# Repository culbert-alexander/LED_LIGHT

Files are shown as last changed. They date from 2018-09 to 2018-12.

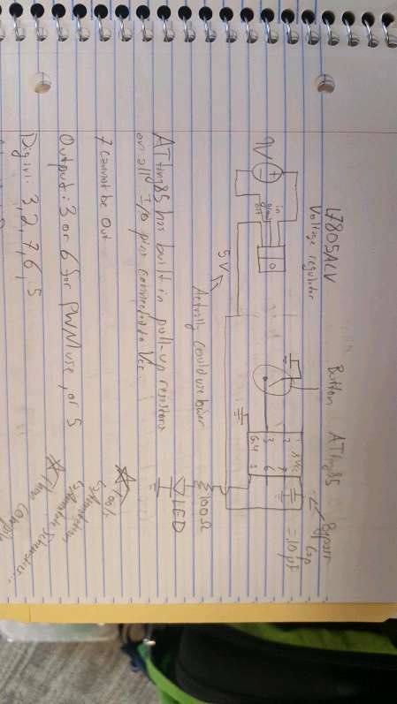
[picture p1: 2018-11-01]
Electronics/circuit.jpg

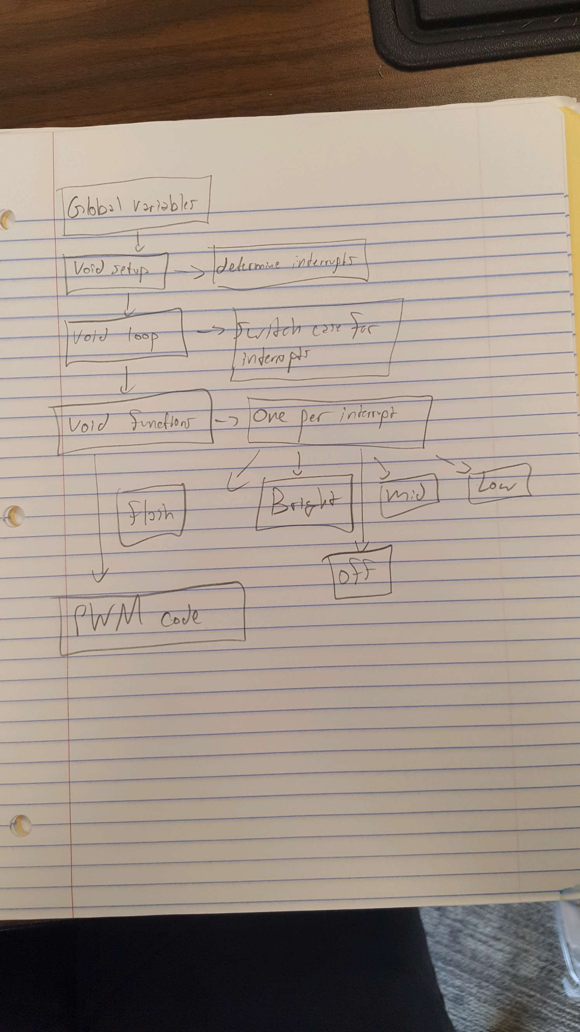
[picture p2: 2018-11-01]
Software/software.jpg

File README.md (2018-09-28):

# LED_LIGHT
Project for Duke University BME 590L
Goal is to build a self-contained batery powered variable light intensity LED.
Must have button exposed.
Must have 5 settings: off, bright, medium bright, low bright, flash at 2 hz.
Certain constraints: <= 9 V, <= 1 lb, < 6 in, <= $50, single PCB, replaceable battery

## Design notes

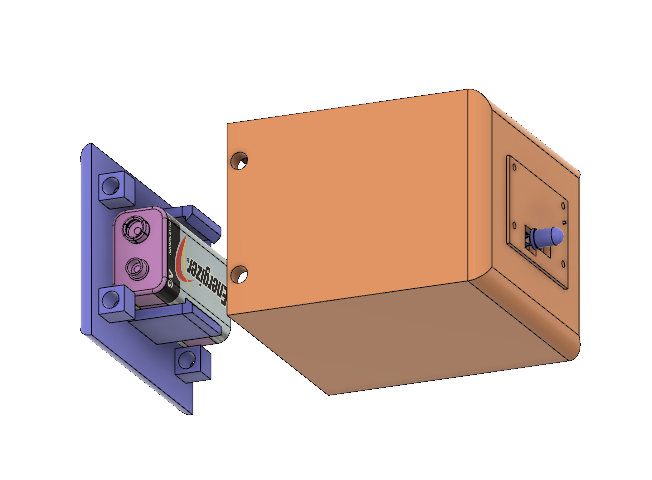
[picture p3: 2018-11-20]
Mechanical/Case_Image.PNG

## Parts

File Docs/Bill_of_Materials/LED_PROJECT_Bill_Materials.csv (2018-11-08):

Comment | Description | Designator | Footprint | LibRef | Quantity
SSW-104-02-T-D | SQ Post Socket, Through-hole, Vertical, -55 to 105 degC, 2.54mm Pitch, 8-Pin, Female, RoHS | ATTiny | SMTC-SSW-104-02-X-D | CMP-1023-00342-1 | 1
147694-1 | FSM8JRT=SWITCH,PUSHBUTTON,TACT | Button | TE_FSM8JRT | FSM8JRT | 1
81R0LFJ0511WPN081T | Aluminum Electrolytic Capacitor, 1 uF +/- 5%, 50 V, -40 to 105 degC, 2 Pin THD, Dia 5 mm, Body Length 11 mm, Tape and Reel | ByCap | FHTE-8-0511-2_M | CMP-0909-00001-1 | 1
151053RS03000 | THT LED round mono-color waterclear, WL-TMRW ,Red | LED | Type 5mm | CMP-1489-00007-1 | 1
FMP300FRF73-82K | Metal Film Resistor, 82 KOhm +/-1%, 3 W, -55 to 155 degC, 2-Pin THD, RoHS, Tape and Reel | LEDR | YAGO-FMP300-2_V2 | CMP-1257-00001-1 | 1
PHF-102-01-L-S-002 | Press Fit Socket, Through-hole, Vertical, -55 to 125 degC, 2.54 mm Pitch, 2-Pin, Female, RoHS | Power | SMTC-PHF-102-01-X-S-002 | CMP-1023-00103-1 | 1
L7805ACV | Positive Voltage Regulator, 5V, 3-Pin TO-220 | PowerReg | TO220 | CMP-0244-00484-1 | 1

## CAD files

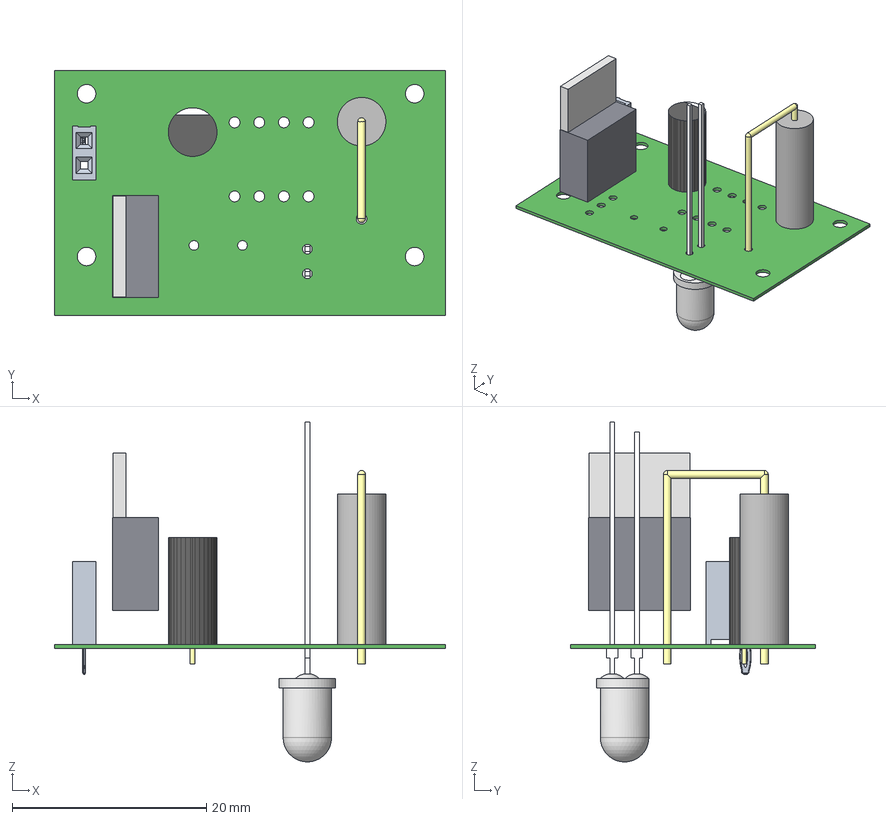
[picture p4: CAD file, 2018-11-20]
Hardware/LED_PROJECT.step
40.3 x 25.3 x 35.0 mm
Board
PHF-102-01-X-S-002
Extruded x 4
WL-TMRW_5mm

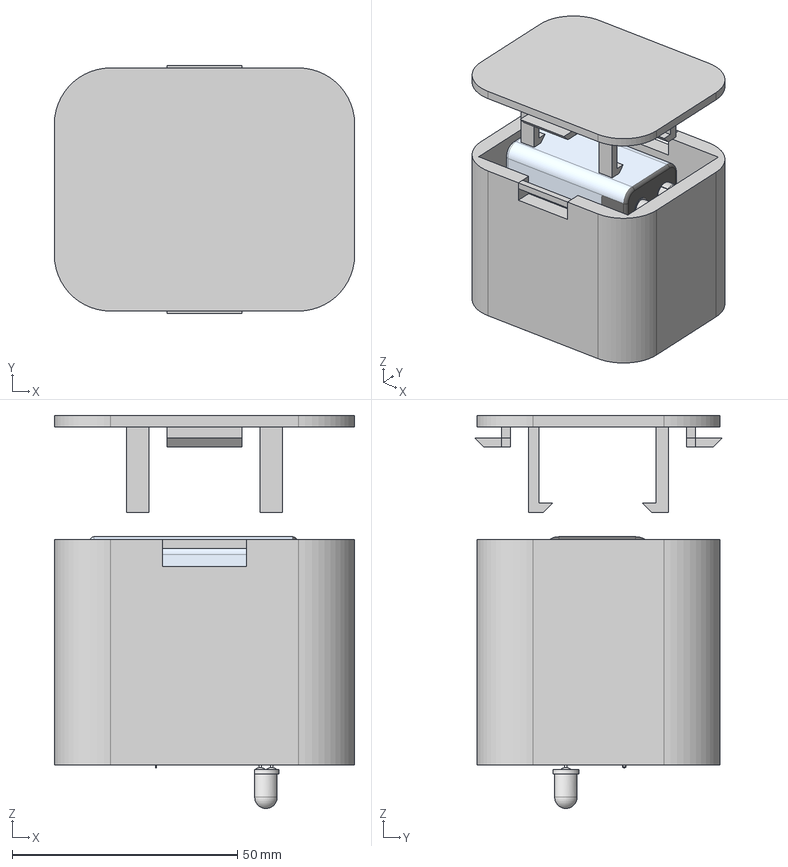
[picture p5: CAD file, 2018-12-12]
Mechanical/Light_Case_2.0.step
66.7 x 55.0 x 87.2 mm
Board
PHF-102-01-X-S-002
Extruded
Extruded (1)
WL-TMRW_5mm
Extruded (2)
Extruded (3)
Siding
9V_1
Lid (1)

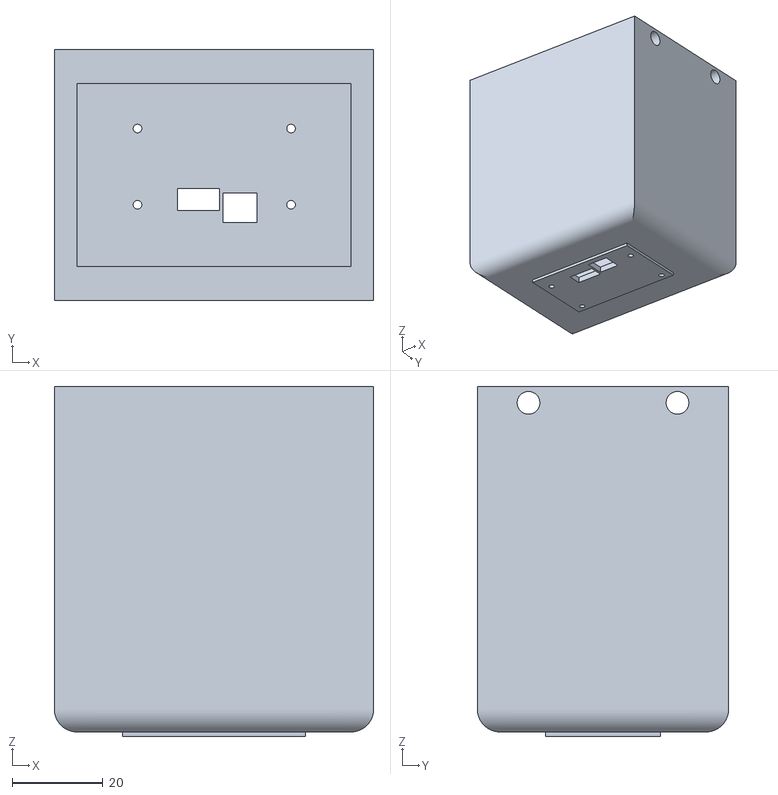
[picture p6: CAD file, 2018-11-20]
Mechanical/Face.stl
70.3 x 55.3 x 77.0

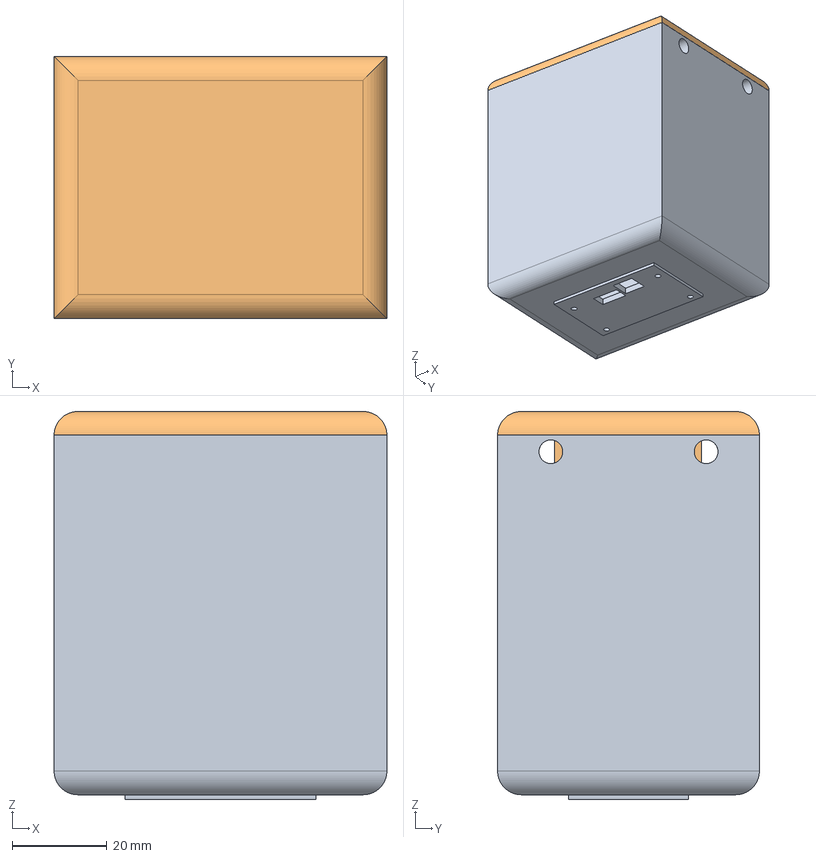
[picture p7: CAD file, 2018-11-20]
Mechanical/LED_PROJECT v9.step
70.3 x 55.3 x 81.9 mm
Lid

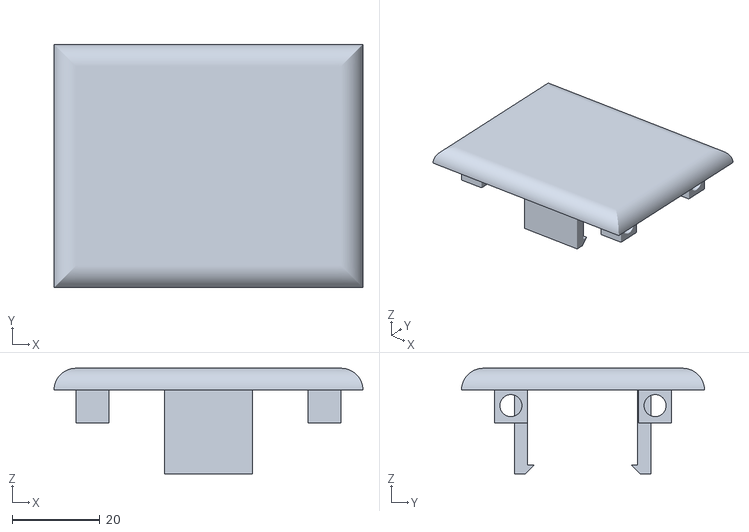
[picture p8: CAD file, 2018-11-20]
Mechanical/Lid.stl
70.3 x 55.3 x 24.0

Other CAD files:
Mechanical/Face.f3d
Mechanical/Lid.f3d

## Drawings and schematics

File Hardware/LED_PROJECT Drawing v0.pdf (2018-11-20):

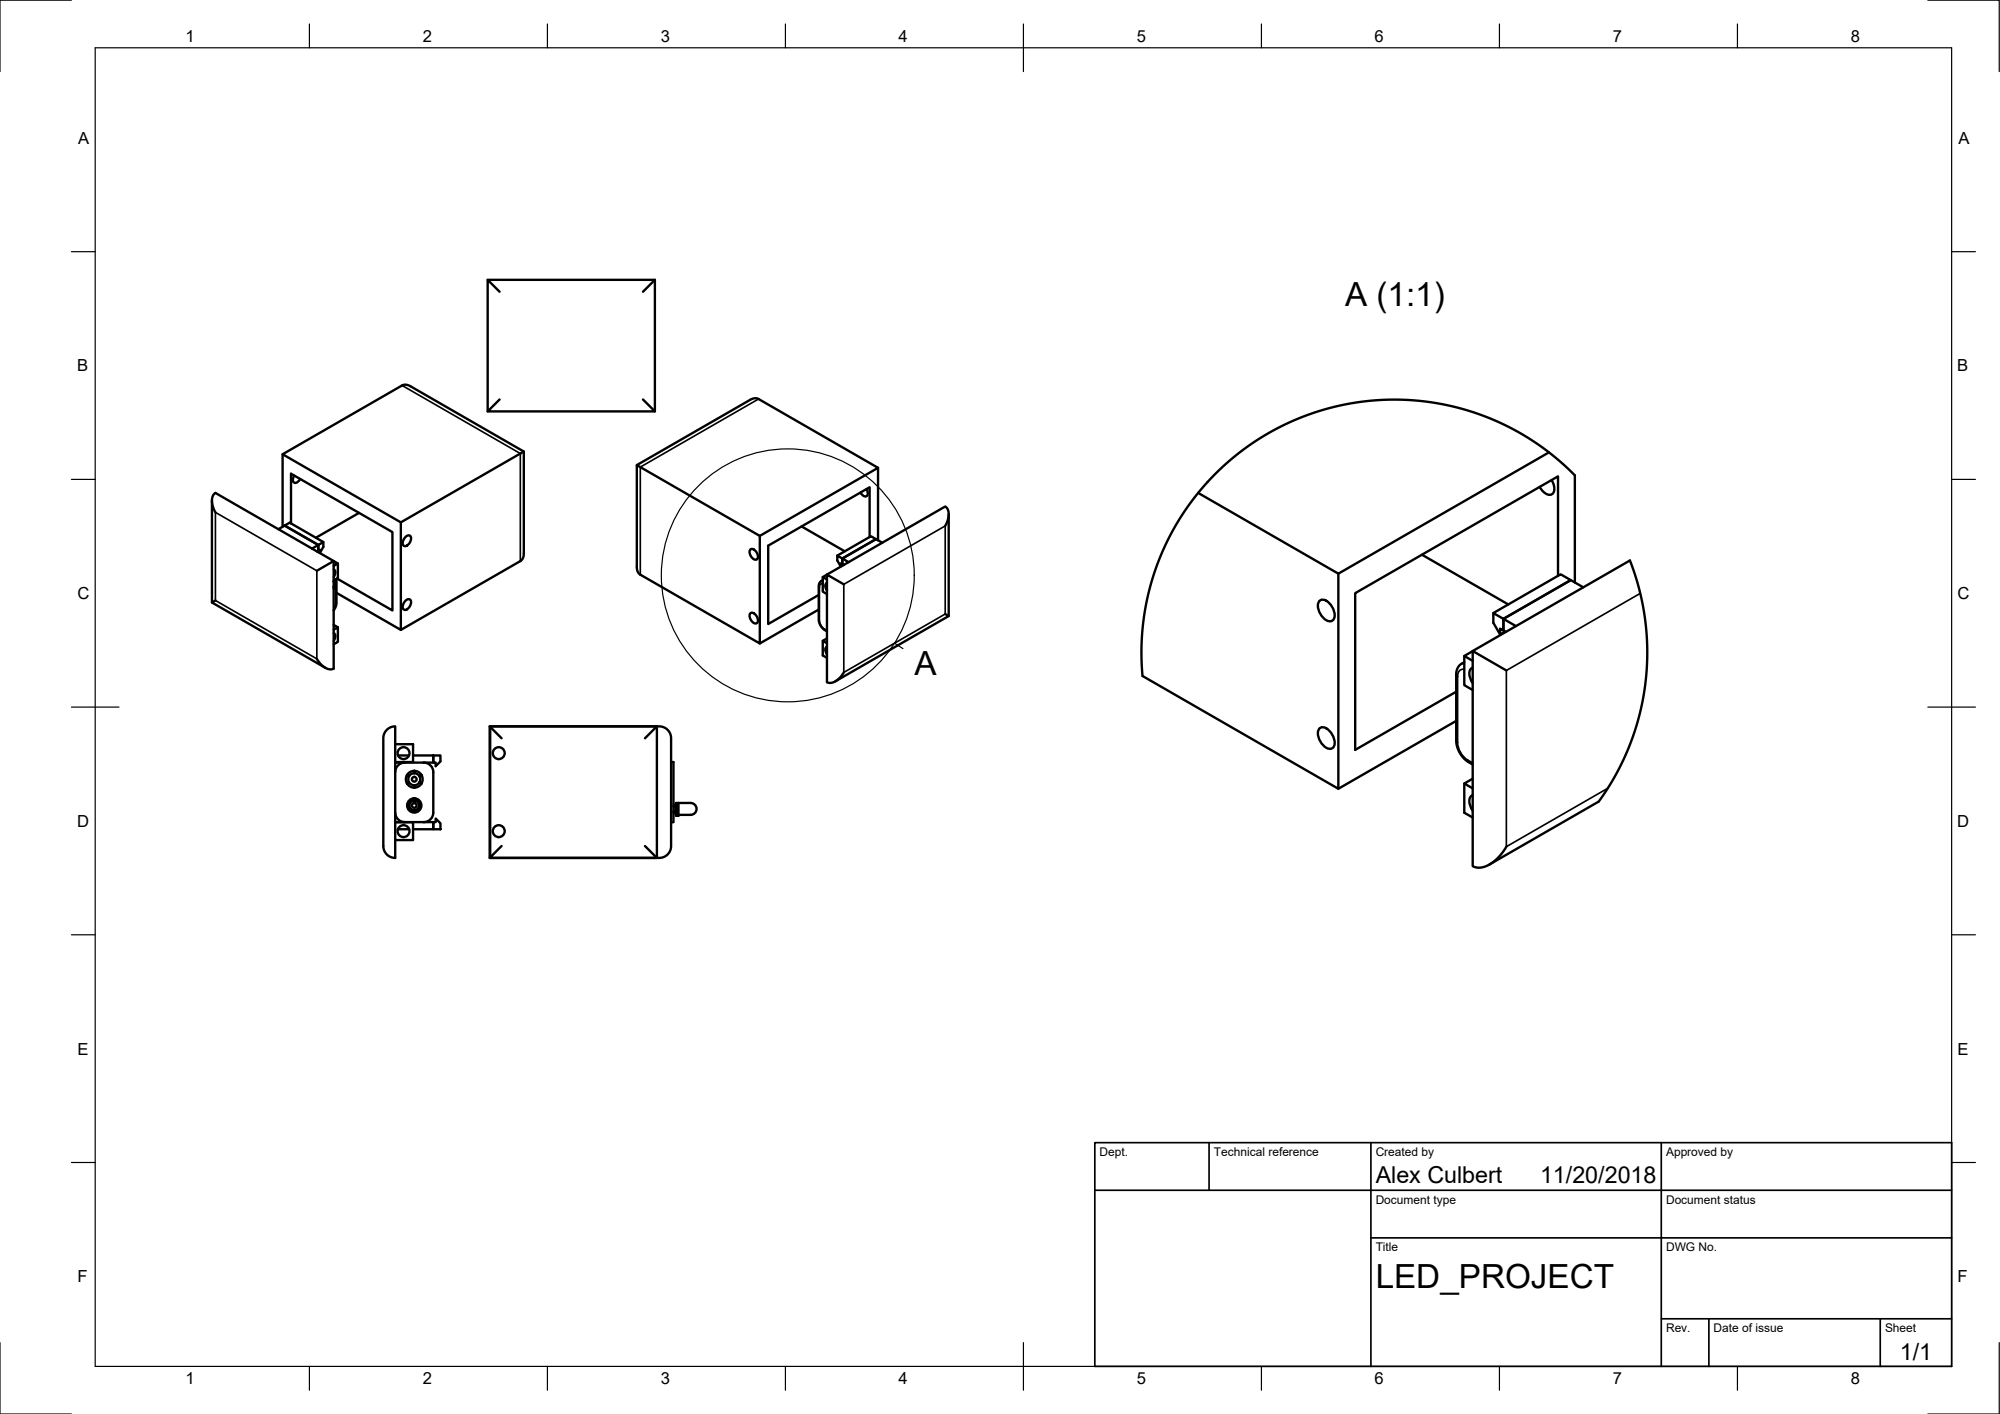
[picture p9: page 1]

Dept. | Technical reference | Created by Alex Culbert 11/20/2018 | Approved by

Document type | Document status

Title LED_PROJECT | DWG No.

Rev. | Date of issue | Sheet 1/1

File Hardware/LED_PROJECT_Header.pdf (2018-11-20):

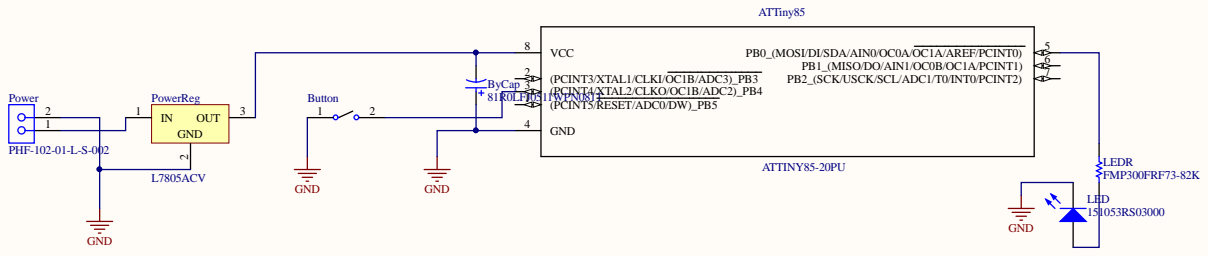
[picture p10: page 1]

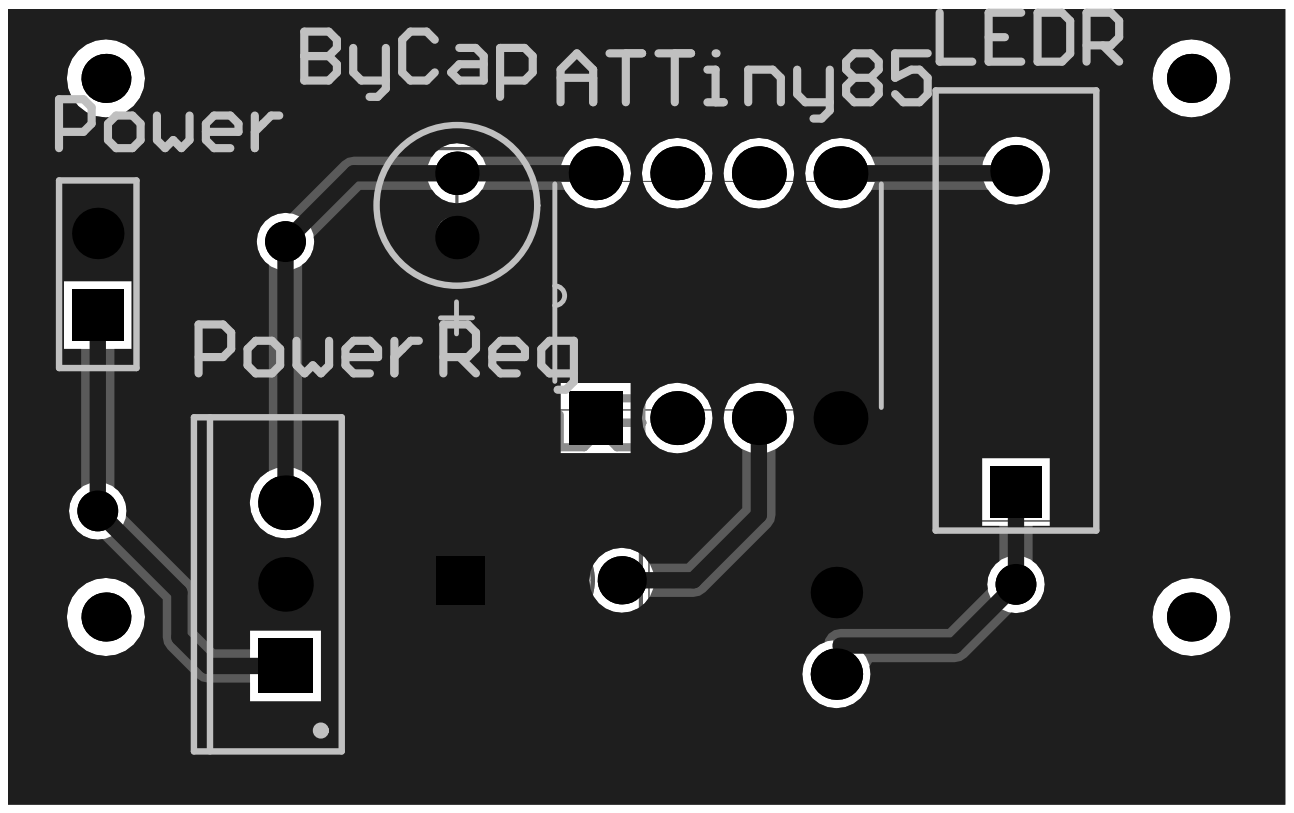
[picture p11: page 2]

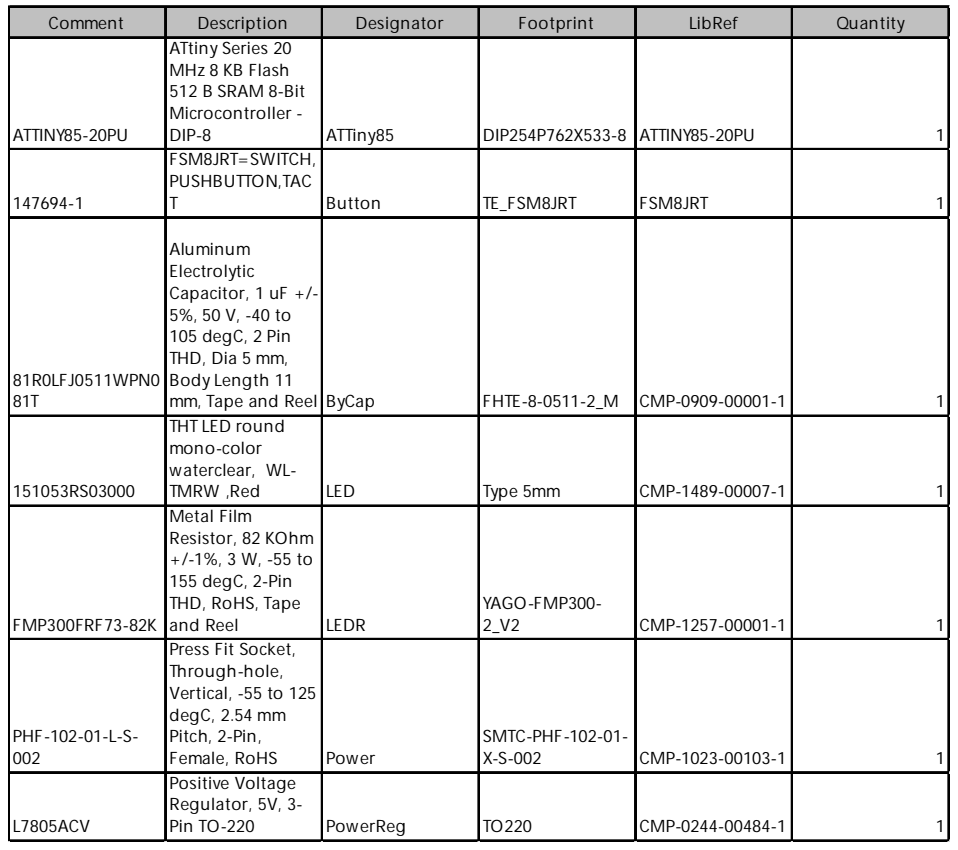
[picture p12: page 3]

Comment | Description | Designator | Footprint | LibRef | Quantity
ATTINY85-20PU | ATtiny Series 20 MHz 8 KB Flash 512 B SRAM 8-Bit Microcontroller -DIP-8 | ATTiny85 | DIP254P762X533-8 | ATTINY85-20PU | 1

147694-1 | FSM8JRT=SWITCH, PUSHBUTTON,TAC T | Button | TE_FSM8JRT | FSM8JRT | 1

81R0LFJ0511WPN0 81T | Aluminum Electrolytic Capacitor, 1 uF +/-5%, 50 V, -40 to 105 degC, 2 Pin THD, Dia 5 mm, Body Length 11 mm, Tape and Reel | ByCap | FHTE-8-0511-2_M | CMP-0909-00001-1 | 1

151053RS03000 | THT LED round mono-color waterclear, WL-TMRW ,Red | LED | Type 5mm | CMP-1489-00007-1 | 1

FMP300FRF73-82K | Metal Film Resistor, 82 KOhm +/-1%, 3 W, -55 to 155 degC, 2-Pin THD, RoHS, Tape and Reel | LEDR | YAGO-FMP300-2_V2 | CMP-1257-00001-1 | 1

PHF-102-01-L-S-002 | Press Fit Socket, Through-hole, Vertical, -55 to 125 degC, 2.54 mm Pitch, 2-Pin, Female, RoHS | Power | SMTC-PHF-102-01-X-S-002 | CMP-1023-00103-1 | 1

L7805ACV | Positive Voltage Regulator, 5V, 3-Pin TO-220 | PowerReg | TO220 | CMP-0244-00484-1 | 1

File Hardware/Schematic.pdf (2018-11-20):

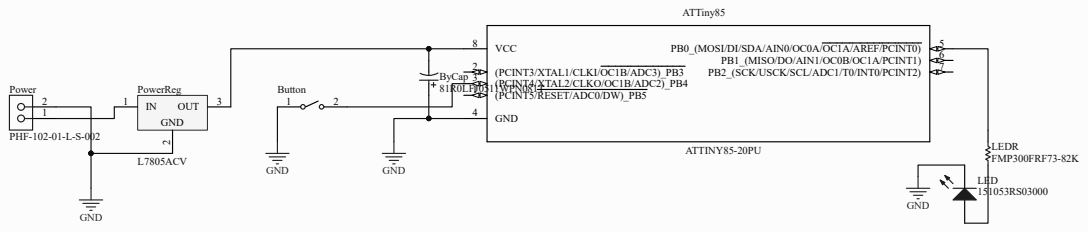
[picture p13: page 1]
Title; OUT; GND; PowerReg; L7805ACV; Power; PHF-102-01-L-S-002; LED 151053RS03000; LEDR FMP300FRF73-82K; Button; ByCap 81R0LFJ0511WPN081T; PB2_(SCK/USCK/SCL/ADC1/T0/INT0/PCINT2); 7 PB1_(MISO/DO/AIN1/OC0B/OC1A/PCINT1); 6 PB0_(MOSI/DI/SDA/AIN0/OC0A/OC1A/AREF/PCINT0); GND 4; (PCINT5/RESET/ADC0/DW)_PB5 1; (PCINT4/XTAL2/CLKO/OC1B/ADC2)_PB4 3; (PCINT3/XTAL1/CLKI/OC1B/ADC3)_PB3 2; VCC 8; ATTiny85; ATTINY85-20PU

Size Letter | Number | Revision

Date: 11/20/2018 | Sheet of
File: C:\Data\..\LED_PROJECT.SchDoc | Drawn By:

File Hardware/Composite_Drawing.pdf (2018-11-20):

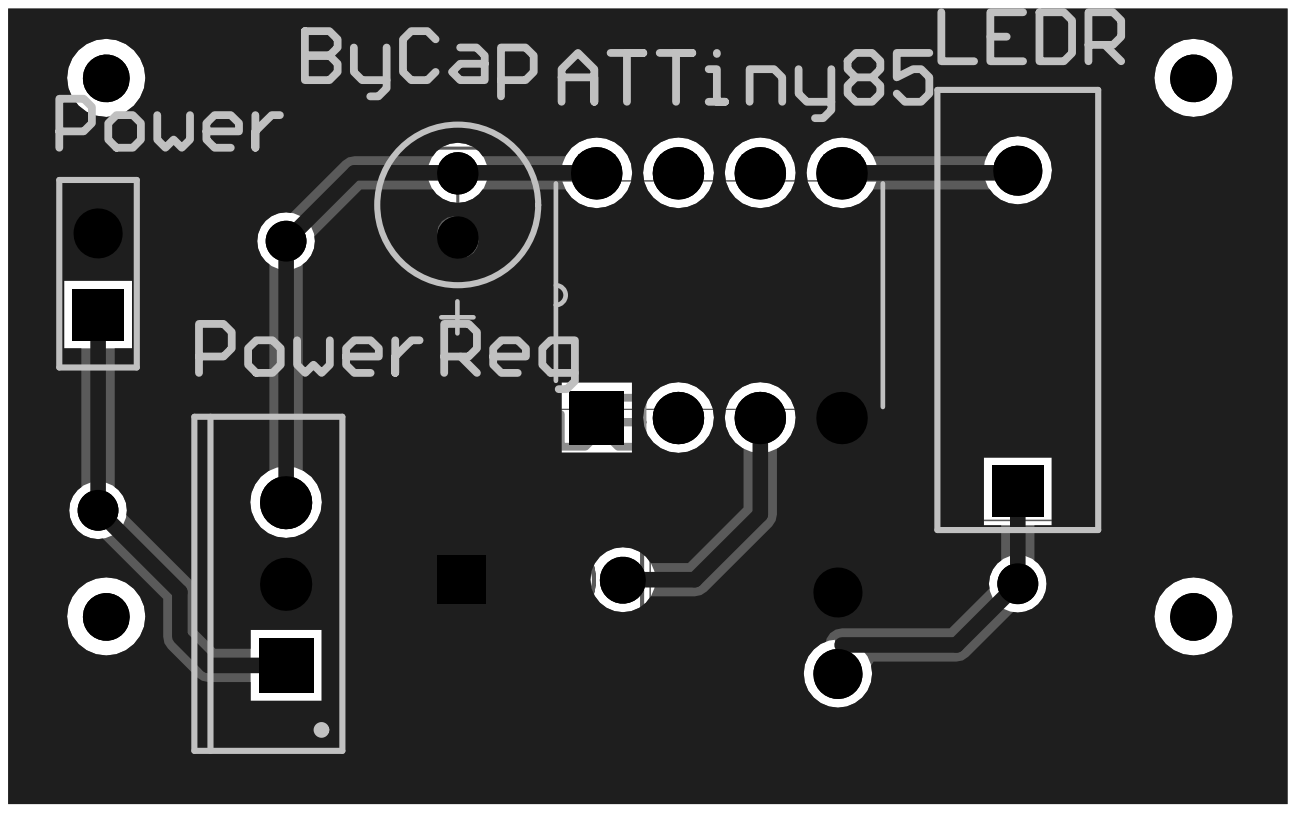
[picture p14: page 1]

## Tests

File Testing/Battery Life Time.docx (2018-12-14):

Alexander Culbert

12-14-2018

BME 590L

Battery Life Time

Battery capacity for a 9V = 500 mAh.

Battery drain at rest: 5.57 mA

Battery drain at high: 17.93 mA

In an ideal situation:

Max battery life time while at rest:

500 mAh / 5.57 mA = 89 hours and 46 minutes

Max battery life time while operating at high:

500 mAh / 17.93 mA = 27 hours and 53 minutes

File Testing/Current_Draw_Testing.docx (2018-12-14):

Alexander Culbert

12-14-2018

BME 590L

Current Draw Testing

At rest: 5.57 mA

At low: 9.54 mA

At medium: 12.41 mA

At high: 17.93 mA

Flashing 6.81, 17.93 mA alternating

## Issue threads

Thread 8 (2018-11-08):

Milestone 04 PCB

culbert-alexander, 2018-11-08:
Hopefully the PCB is at a good start. Known issues may be the clearance, and whether or not the bottom layer is actually all copper. I plan on using through-hole for everything. MCU code to come later once I figure out ATTiny.

sphaerobolus, 2018-11-12:
FYI, our ATTinys are SMT.

The 2-row header you've used for the Tiny is a recipe for a headache. Best to use the correct footprint.

Don't need to parallel traces on top and bottom of board. Put a trace on either side, but not both.

Bypass cap should be close to the Tiny's power pin, between pin and ground. The bypass cap here is in between power supply and the Tiny's power pin. This will block the DC power, no good.

brinnaebent, 2018-11-12:
Why do you have a route on top/bottom (the same route?). It looks like you shouldn't need that 2nd layer at all.
Connections okay.
Consider clearance around header for whatever microcontroller you are plugging into it.

culbert-alexander, 2018-11-20:
PCB should be all but fixed at this point. Please note I'm using through-hole ATTiny85s that I bought and plan on soldering a socket in. The footprint chosen was pulled from DigiKey's ATTiny85 library.

sphaerobolus, 2018-11-20:
Looks good now. One thing we must have missed before: I don't see a pullup or pulldown resistor on your momentary switch. Do you have an internal?

culbert-alexander, 2018-11-20:
Yep planning on using the ATTiny85's internal pullup resistors

culbert-alexander, 2018-11-30:
Shorted my PCB soldering. Feeling very foolish now...

mlp6, 2018-11-30:
Uh oh... salvageable?

culbert-alexander, 2018-12-03:
Unclear. I believe having the top plate being ground with little traces for everything else has caused me to have significant overlap in my solder between the trace and the large ground plate. Thus, the short. I've attached a picture of my PCB, though I know just looking at it may not help.
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

At this point, is my best move to slightly redo my PCB with a ground trace connecting all the grounds, versus the top plate? This would allow my soldering to be this messy and not connect any pins to ground (assuming my assumption here is correct, in that that's the issue).

brinnaebent, 2018-12-03:
Hi Alex,

I think your issue is definitely messy soldering. The solder should be a small bubble and shouldn’t overlap with the rest of your board. From the picture, it looks like you are shorted in at least 3 places. I think your best bet is to re-do the board and be very thoughtful when soldering your next board.

On Dec 2, 2018, at 9:59 PM, Alexander Culbert <notifications@github.com<mailto:notifications@github.com>> wrote:

Unclear. I believe having the top plate being ground with little traces for everything else has caused me to have significant overlap in my solder between the trace and the large ground plate. Thus, the short. I've attached a picture of my PCB, though I know just looking at it may not help.
[img_4999]<https://urldefense.proofpoint.com/v2/url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>

At this point, is my best move to slightly redo my PCB with a ground trace connecting all the grounds, versus the top plate? This would allow my soldering to be this messy and not connect any pins to ground (assuming my assumption here is correct, in that that's the issue).

—
You are receiving this because you commented.
Reply to this email directly, view it on GitHub<https://urldefense.proofpoint.com/v2/url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>, or mute the thread<https://urldefense.proofpoint.com/v2/url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>.

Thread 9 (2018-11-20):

Milestone 05 CAD

culbert-alexander, 2018-11-20:
The mechanical casing should be at a good starting point. I was unable to upload the entire Fusion 360 project due to the 9V battery component I imported, but I have STLs and .f3d files for my lid and main-base. I plan on having some simple screw to connect the PCB to the case and the lid to the main-base.

ps178, 2018-11-23:
Can you move the CAD files under the folder Mechanical as instructed for milestone 05?

I think your CAD looks good! It might be too tall? But you can adjust that when you have the physical PCB, etc.

culbert-alexander, 2018-11-25:
Yup that's on me, my bad! The CAD files are now under Mechanical.
And the longest dimension is 3 inches, I think the picture makes it look a lot longer than it really is!

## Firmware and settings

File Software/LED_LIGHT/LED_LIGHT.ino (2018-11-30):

// I was inspired by online resources from https://thewanderingengineer.com/2014/08/11/pin-change-interrupts-on-attiny85/
// This guy is Matt Walker at University of Oklahoma
// I also used the ATTiny85 Datasheet a whole bunch
// Finally, Dr. Palmeri's example code at https://github.com/mlp6/Fundamentals-BME-Design/blob/master/PrototypingSkills/software.ino
// Besides their help the rest is me at Alexander Culbert

#include <avr/io.h>
#include <avr/interrupt.h>
#include <avr/sleep.h>

// Look at me preprocess whoo whoo woooo
#define PIN_OUT PCINT0    // Pin 0
#define PIN_IN PCINT4     // Pin 4
#define PWM_Max_Val 255   // PWM Max is 255

// The initial, changeable values
int current_mode = 0;     // 0 = Off, 1 = On, 2 = Medium On, 3 = Low On, 4 = 2 Hz Flashing
int PWM_Current_Val = 0;  // Initally PWM is at 0
unsigned long old_time = 0;
unsigned long current_time = 0;
const long flash_rate = 50;
int flash_state = 0;


void setup() {
  cli(); //Disable interrupts ~briefly~
  // Goal is to enable interrupts and pullup resistors on input pin 4
  // Also set pin 0 as an output

  GIMSK = 0b00100000;                 // Enables interrupts
  PCMSK = 0b000010000;                // Turns on interrupts for Pin 4
  DDRB = 0b111101111;                 // Input or Output (Pin 0 is output)
  pinMode(PIN_OUT, OUTPUT);           // Pin is output
  digitalWrite(PIN_OUT, LOW);         // Initial LED is off
  PINB = 0b000010000;                 // Allows for Pin B Functionality on Pin 4
  PORTB = 0b000010000;                // Enables Pull-Up Resistor on Pin 4

  // DDxn determines if pin is input or output. If DDxn is logic one, Pxn is output. If zero. then input.
  // If PORTxn is login one while pin is input, then you get the pull-up resistor
  // If PORTxn is logic zero when pin is output, then port is driven low (zero). If logic one, then driven high.

  // ADCSRA &= ~_BV(ADEN); // idk if this is needed

  sei(); //Enable interrupts
}

void loop() {
  switch_statement();
}

void switch_statement() {
  switch (current_mode) {
    case 0:
      PWM_Current_Val = 0;
      analogWrite(PIN_OUT, PWM_Current_Val);
      set_sleep_mode(SLEEP_MODE_PWR_DOWN);
      sleep_enable();
      sleep_bod_disable();
      sleep_cpu();
      break;
    case 1:
      sleep_disable();
      PWM_Current_Val = PWM_Max_Val;
      analogWrite(PIN_OUT, PWM_Current_Val);
      break;
    case 2:
      PWM_Current_Val = int(PWM_Max_Val / 2);
      analogWrite(PIN_OUT, PWM_Current_Val);
      break;
    case 3:
      PWM_Current_Val = int(PWM_Max_Val / 4);
      analogWrite(PIN_OUT, PWM_Current_Val);
      break;
    case 4:
      PWM_Current_Val = PWM_Max_Val;
      flash();
      break;
  }
}

ISR(PCINT0_vect) {
  if (digitalRead(PIN_IN)) {
    current_mode = current_mode + 1;
    if (current_mode > 4) {
      current_mode = 0;
    }
  }
}


void flash() {
  current_time = millis();
  if (current_time - old_time >= flash_rate) {
    old_time = current_time;
    if (flash_state == 0) {
      flash_state = PWM_Current_Val;
    }
    else {
      flash_state = 0;
    }
    analogWrite(PIN_OUT, flash_state);
  }
}

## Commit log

2018-11-01 Circuit
    Paper sketch of my circuit.
2018-11-01 Software Diagram
    Flow chart for software.
2018-11-08 Hardware PCB
    Uploaded the PCB ECAD schematic.
    [LED_PROJECT.PcbDoc, LED_PROJECT.SchDoc, LED_PROJECT_Header.PrjPCB]
2018-11-08 Bill_Materials
    Uploaded the PCB Bill of Materials
    [LED_PROJECT_Bill_Materials.csv]
2018-11-15 Updated LED PCB
    [LED_PROJECT.PcbDoc, LED_PROJECT.SchDoc, LED_PROJECT_Header.PrjPCB]
2018-11-20 Update LED PCB
    I think I fixed most of the major issues...
    [LED_PROJECT.PcbDoc]
2018-11-20 Added Updated ECAD and New CAD
    Updated ECAD Files:
    Schematic, LED_PROJECT_Header.PrjPCBStructure, Composite_Drawing.pdf, LED_PROJECT_Header, Bill_of_Materials, LED_PROJECT_3D, LED_PROJECT, LED_PROJECT, LED_PROJECT_Header, LED_PROJECT_Header
    New CAD Files:
    Case_Image, Lid.stl, Face.stl, Lid, Face, LED_PROJECT v9.step
    Please not due to imported 9V battery, I was unable to upload the Fusion 360 Project file.
    [Face.f3d, Face.stl, LED_PROJECT v9.step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]
2018-11-20 Added 2D Drawing
    Added the 2D CAD Drawing.
2018-11-25 CAD Files
    Uploaded CAD files to proper folder.
    [Face.f3d, Face.stl, LED_PROJECT v9.step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]
2018-11-25 Arduino Code
    Added my initial attempt at coding an ATTiny85.
2018-11-30 Fixed code
    Code is now working.
    [LED_LIGHT.ino]
2018-12-03 Removed ground plate pour + made trace
    Due to an inability to solder really small objects, I removed my ground plate pour that was causing me to short my PCB and created a trace out of it. This will hopefully give me more breathing room when I solder, as now every trace isn't surrounded by ground.
    [LED_PROJECT.PcbDoc]
2018-12-03 Moved drill holes
    Moved the drill holes to a better location
    [LED_PROJECT.PcbDoc]
2018-12-03 Fixed my PCB
    Widened by routes.
    [LED_PROJECT.PcbDoc, LED_PROJECT_Header.PrjPCB]
2018-12-03 Fixed PCB again
    See title
    [LED_PROJECT.PcbDoc, LED_PROJECT_Header.PrjPCB]
2018-12-12 Created my case 2.0
    Created a new light case to better suit my enlarged PCB and not need as many moving parts.
    [Light_Case_2.0.step]
2018-12-14 Current Draw Test
    Tested the current draw on all states.
2018-12-14 Tested Battery Life Time
    Calculated an estimate for the battery life time.
